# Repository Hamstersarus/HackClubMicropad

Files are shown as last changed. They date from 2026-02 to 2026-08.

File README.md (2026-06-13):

# HackClubMicropad

---

## Table of Contents

- [Overview](#overview)
- [Photos](#photos)
- [Bill of Materials](#bill-of-materials)

---

## Overview

The HackClub Micropad is a compact, USB-HID macropad intended for programmable shortcut input.
It was designed from scratch in KiCad and manufactured via JLCPCB. Firmware runs on CircuitPython.
It is a keybord with a programmable OLED screen, 6 keys, and a rotary encoder.
It is a fun, memorable, and beginner friendly productivity tool.

**Key features:**

- Seeed Studio XIAO RP2350 microcontroller
- Mechanical key switches (MX-compatible footprints)
- Rotary encoder with push-button
- Onboard NeoPixel (WS2812B) RGB indicator
- USB-C connectivity via the XIAO module
- 3D-printed enclosure (FDM, PLA)

---

## Photos

**PCB Top View**

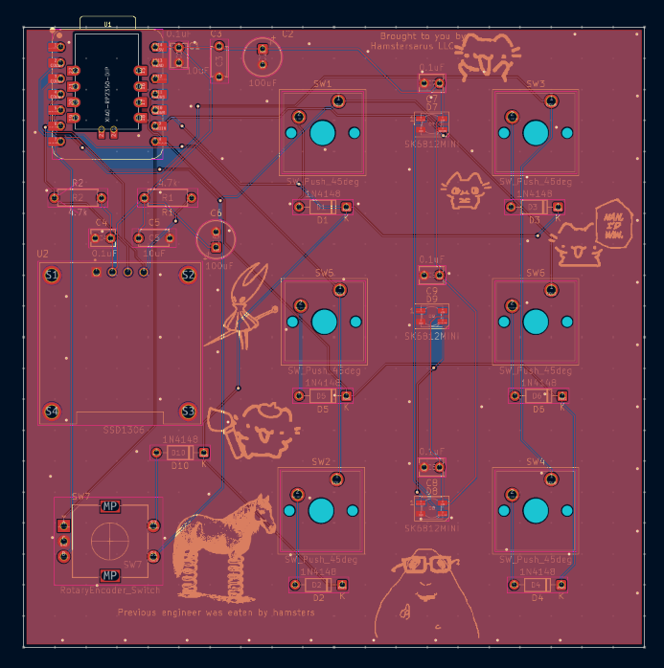
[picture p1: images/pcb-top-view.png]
PCB top view


**Assembled Board**

snapshot_assembly

**Case**

snapshot_case_only_back

snapshot_case_only_front

---

### Bill of Materials

| Part Number | Description | Quantity | Ordering Location |
| :--- | :--- | :--- | :--- |
| 1597-102010550-ND | Seeed Studio XIAO RP2350 microcontroller (DIP) | 1 | [DigiKey](https://www.digikey.com/en/products/result?keywords=1597-102010550-ND) |
| 4809-EC11E15204A3-ND | EC11 rotary encoder with push-button, 5-pin | 1 | [DigiKey](https://www.digikey.com/en/products/detail/alps-alpine/EC11E15204A3/21721644) |
| 3086-MDOB128064V2V-YI-ND | SSD1306 OLED Screen | 1 | [DigiKey](https://www.digikey.com/en/products/detail/midas-displays/MDOB128064V2V-YI/20842029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) |
| 1528-1541-ND | RGB LED with integrated controller (SK6812MINI) | 3 | [DigiKey](https://www.digikey.com/en/products/detail/adafruit-industries-llc/2686/5804107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) |
| 1644-MX2A-E1NW-ND | Push button switch, normally open, 45° tilted | 6 | [DigiKey](https://www.digikey.com/en/products/detail/cherry-americas-llc/MX2A-E1NW/21738396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) |
| 1N4148FS-ND | 100V 0.15A standard switching diode, DO-35 | 7 | [DigiKey](https://www.digikey.com/en/products/detail/onsemi/1N4148/458603?s=N4IgTCBcDaIIwDkAsckA4BiBlAtAgIiALoC%2BQA) |
| 490-8808-ND | Unpolarized capacitor, 0.1uF | 5 | [DigiKey](https://www.digikey.com/en/products/detail/murata-electronics/RDER71E104K0K1H03B/4770963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) |
| 399-C324C106K3R5TA7301CT-ND | Unpolarized capacitor, 10uF | 2 | [DigiKey](https://www.digikey.com/en/products/detail/kemet/C324C106K3R5TA7301/12699356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) |
| 732-8825-1-ND | Polarized capacitor, 100uF | 2 | [DigiKey](https://www.digikey.com/en/products/result?keywords=732-8825-1-ND) |
| 56-CCF554K70FKE36CT-ND | Resistor, 4.7k | 2 | [DigiKey](https://www.digikey.com/en/products/detail/vishay-beyschlag-draloric-bc-components/CCF554K70FKE36/28262019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) |

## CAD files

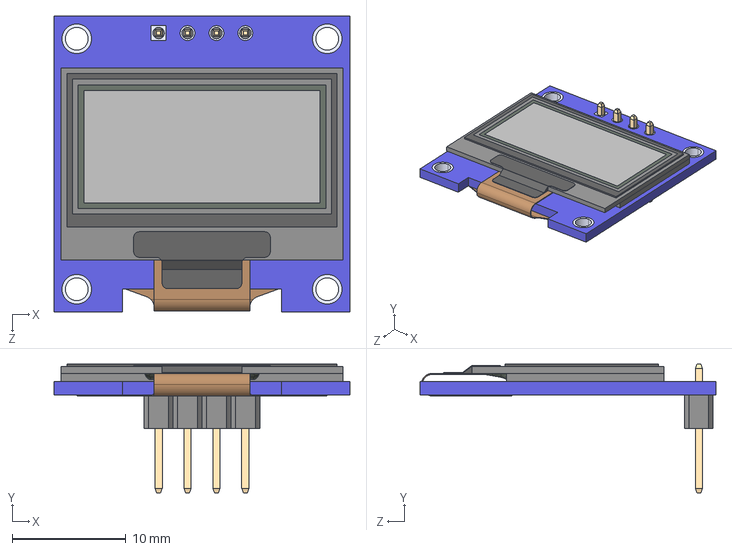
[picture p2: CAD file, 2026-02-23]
KiCAD/Symbols/DM-OLED096-636/DM-OLED096-636.step
26.0 x 11.3 x 26.0 mm
DM-OLED096-636_Module
DM-OLED096-636_Panel

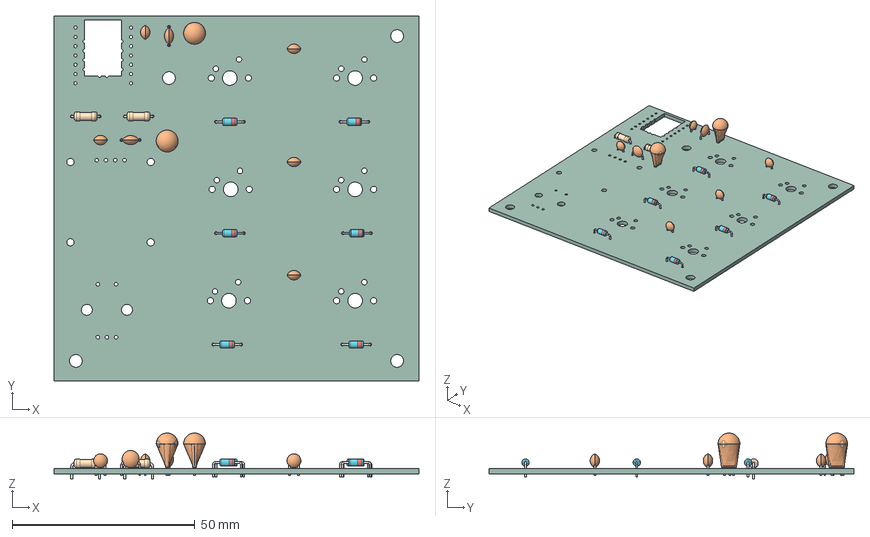
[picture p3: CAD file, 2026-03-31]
Mechanical/Models/Macropad.step
100.0 x 100.0 x 12.6 mm
C_Disc_D3.8mm_W2.6mm_P2.50mm x 5
D_DO-35_SOD27_P7.62mm_Horizontal x 6
R_Axial_DIN0207_L6.3mm_D2.5mm_P7.62mm_Horizontal x 2
C_Disc_D4.7mm_W2.5mm_P5.00mm x 2
CP_Radial_Tantal_D6.0mm_P2.50mm x 2
Macropad_PCB

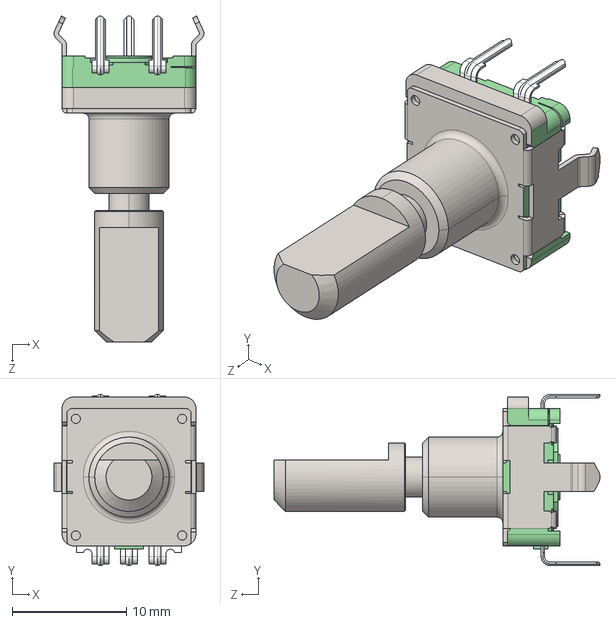
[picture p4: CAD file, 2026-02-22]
KiCAD/Symbols/EC1110120201_Rotary_Encoder/3D/EC1110120201.stp
13.1 x 15.0 x 28.5 mm

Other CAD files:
KiCAD/Symbols/EC1110120201_Rotary_Encoder/Allegro/ec1110120201.psm
KiCAD/Symbols/EC1110120201_Rotary_Encoder/DEHDL/ec1110120201/chips/chips.prt

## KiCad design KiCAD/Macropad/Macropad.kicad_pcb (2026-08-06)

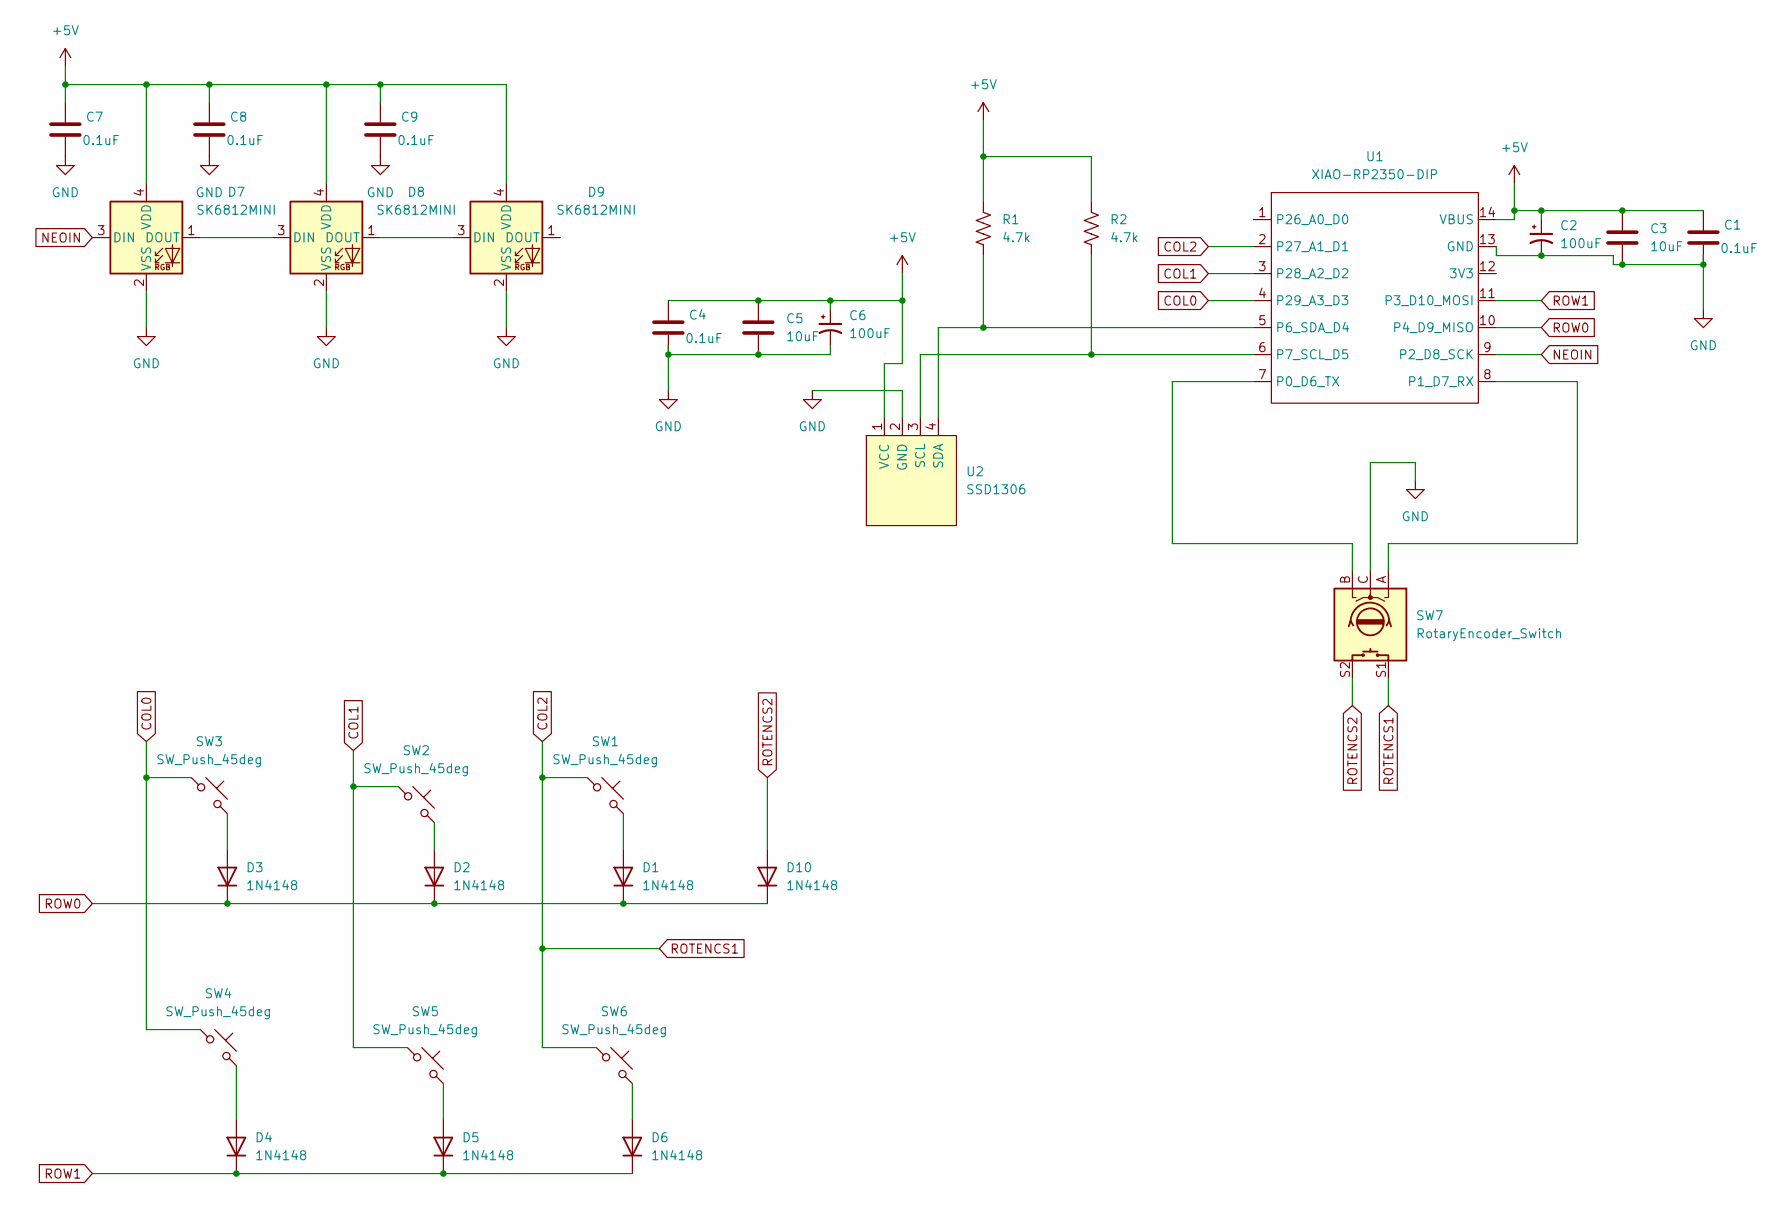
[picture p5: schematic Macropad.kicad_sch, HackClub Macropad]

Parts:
C1, C4, C7, C8, C9: 0.1uF; C_Disc_D3.8mm_W2.6mm_P2.50mm; Part_Number 490-8808-ND
C2, C6: 100uF; CP_Radial_Tantal_D6.0mm_P2.50mm; Part_Number 732-8825-1-ND
C3, C5: 10uF; C_Disc_D4.7mm_W2.5mm_P5.00mm; Part_Number 399-C324C106K3R5TA7301CT-ND
D1, D2, D3, D4, D5, D6, D10: 1N4148; D_DO-35_SOD27_P7.62mm_Horizontal; Part_Number 1N4148FS-ND
D7, D8, D9: SK6812MINI; LED_SK6812MINI_PLCC4_3.5x3.5mm_P1.75mm; Part_Number 1528-1541-ND
R1, R2: 4.7k; R_Axial_DIN0207_L6.3mm_D2.5mm_P7.62mm_Horizontal; Part_Number 56-CCF554K70FKE36CT-ND
SW1, SW2, SW3, SW4, SW5, SW6: SW_Push_45deg; SW_Cherry_MX_1.00u_PCB; Part_Number 1644-MX2A-E1NW-ND
SW7: RotaryEncoder_Switch; RotaryEncoder_Alps_EC11E-Switch_Vertical_H20mm; Part_Number 4809-EC11E15204A3-ND
U1: XIAO-RP2350-DIP; Part_Number 1597-102010550-ND
U2: SSD1306; MODULE_DM-OLED096-636; Part_Number 3086-MDOB128064V2V-YI-ND

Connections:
+5V: C1.1, C2.1, C3.1, C4.1, C5.1, C6.1, C7.1, C8.1, C9.1, D7.4 (VDD), D8.4 (VDD), D9.4 (VDD), R1.2, R2.2, U1.14 (VBUS), U2.1 (VCC)
COL0: SW3.1, SW4.1, U1.4 (P29_A3_D3)
COL1: SW2.1, SW5.1, U1.3 (P28_A2_D2)
COL2: SW1.1, SW6.1, SW7.S1, U1.2 (P27_A1_D1)
GND: C1.2, C2.2, C3.2, C4.2, C5.2, C6.2, C7.2, C8.2, C9.2, D7.2 (VSS), D8.2 (VSS), D9.2 (VSS), SW7.C, U1.13 (GND), U2.2 (GND)
NEOIN: D7.3 (DIN), U1.9 (P2_D8_SCK)
unnamed: D1.2 (A), SW1.2
unnamed: D2.2 (A), SW2.2
unnamed: D3.2 (A), SW3.2
unnamed: D4.2 (A), SW4.2
unnamed: D5.2 (A), SW5.2
unnamed: D6.2 (A), SW6.2
unnamed: D7.1 (DOUT), D8.3 (DIN)
unnamed: D8.1 (DOUT), D9.3 (DIN)
unnamed: SW7.B, U1.7 (P0_D6_TX)
unnamed: SW7.A, U1.8 (P1_D7_RX)
unnamed: R1.1, U1.5 (P6_SDA_D4), U2.4 (SDA)
unnamed: R2.1, U1.6 (P7_SCL_D5), U2.3 (SCL)
ROTENCS2: D10.2 (A), SW7.S2
ROW0: D1.1 (K), D2.1 (K), D3.1 (K), D10.1 (K), U1.10 (P4_D9_MISO)
ROW1: D4.1 (K), D5.1 (K), D6.1 (K), U1.11 (P3_D10_MOSI)

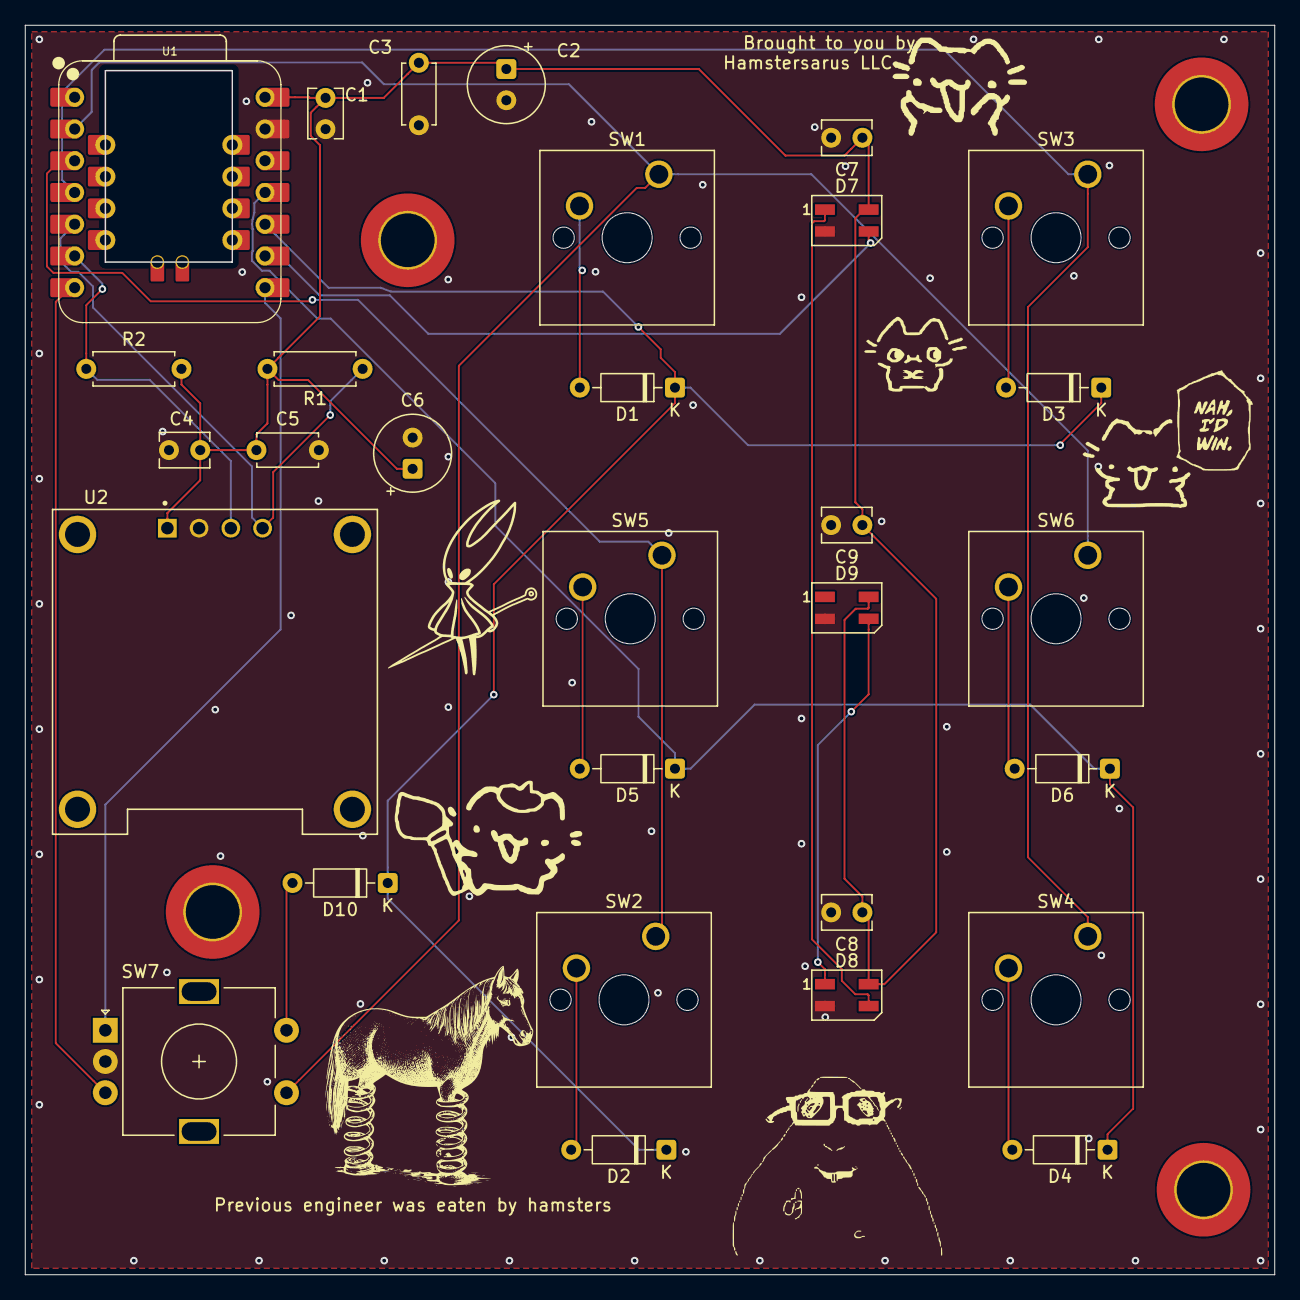
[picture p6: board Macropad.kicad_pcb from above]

Board: 2 copper layers, 100.0 x 100.0 mm, 35 parts (0 on the bottom side), 21 nets.

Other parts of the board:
Brought to you by Hamstersarus LLC: LOGO
REF1, REF2, REF3, REF4: MountingHole_4.3mm_M4_DIN965_Pad_TopBottom

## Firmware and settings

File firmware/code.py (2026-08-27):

## HackClub Macropad — KMK firmware with on-demand video playback
## Board: Seeed XIAO RP2350 (U1)
##
## Matrix (2 rows x 3 cols), diodes anode->switch->COL, cathode->ROW:
##   physical layout is 2 cols x 3 rows; see keymap comments for the mapping.
## Encoder (SW7): A=D6  B=D7  C=GND  (rotation = volume; turn-only)
## OLED (SSD1306, U2) I2C: SDA=D4  SCL=D5  addr=0x3C  (raw driver, 400kHz)
##
## Video: the top-left key sends "PLAY" over the USB *data* serial (enabled in
## boot.py). The host companion (host/play_companion.py) then streams 1024-byte
## OLED frames back over that channel while playing the audio on the computer.
## This module blits incoming frames to the OLED between matrix scans.

import board
import busio
import usb_cdc

from kmk.kmk_keyboard import KMKKeyboard
from kmk.keys import KC, make_key
from kmk.scanners import DiodeOrientation
from kmk.modules import Module
from kmk.extensions.media_keys import MediaKeys

import rotaryio

W, H = 128, 64
FRAME = W * H // 8  # 1024
ADDR = 0x3C
INIT = bytes([0xAE, 0xD5, 0x80, 0xA8, 0x3F, 0xD3, 0x00, 0x40, 0x8D, 0x14,
              0x20, 0x00, 0xA1, 0xC8, 0xDA, 0x12, 0x81, 0x7F, 0xD9, 0xF1,
              0xDB, 0x40, 0xA4, 0xA6, 0x2E, 0xAF])


class OLED:
    """Minimal raw SSD1306 128x64 driver — fast full-frame blits."""
    def __init__(self, scl, sda):
        self.i2c = busio.I2C(scl, sda, frequency=400_000)  # SSD1306 max
        while not self.i2c.try_lock():
            pass
        self.i2c.writeto(ADDR, b"\x00" + INIT)
        self._win = bytes([0x00, 0x21, 0, 127, 0x22, 0, 7])
        self._out = bytearray(1 + FRAME)
        self._out[0] = 0x40

    def show(self, buf):
        self.i2c.writeto(ADDR, self._win)
        self._out[1:] = buf
        self.i2c.writeto(ADDR, self._out)


def _load(path, default=b"\x00" * FRAME):
    try:
        with open(path, "rb") as f:
            d = f.read(FRAME)
        return d if len(d) == FRAME else default
    except OSError:
        return default


class VideoModule(Module):
    """Streams OLED frames from the USB data serial, between KMK scans."""
    def __init__(self):
        self.oled = OLED(board.D5, board.D4)
        self.splash = _load("/splash.bin")
        self.ser = usb_cdc.data
        self.frame = bytearray(FRAME)
        self.view = memoryview(self.frame)
        self.fill = 0

    def during_bootup(self, keyboard):
        self.oled.show(self.splash)

    def before_matrix_scan(self, keyboard):
        ser = self.ser
        if ser is not None and ser.in_waiting:
            self.fill += ser.readinto(self.view[self.fill:])
            if self.fill >= FRAME:
                self.oled.show(self.frame)
                self.fill = 0

    def after_matrix_scan(self, keyboard):
        pass

    def before_hid_send(self, keyboard):
        pass

    def after_hid_send(self, keyboard):
        pass

    def on_powersave_enable(self, keyboard):
        pass

    def on_powersave_disable(self, keyboard):
        pass


keyboard = KMKKeyboard()
keyboard.extensions.append(MediaKeys())

video = VideoModule()
keyboard.modules.append(video)

# Video control keys: signal the host companion over the USB data serial.
def _play(*args):
    if usb_cdc.data is not None:
        usb_cdc.data.write(b"PLAY\n")

def _stop(*args):
    if usb_cdc.data is not None:
        usb_cdc.data.write(b"STOP\n")

make_key(names=("VPLAY",), on_press=_play)
make_key(names=("VSTOP",), on_press=_stop)

# --- Key matrix ---
keyboard.col_pins = (board.D3, board.D2, board.D1)   # COL0, COL1, COL2
keyboard.row_pins = (board.D9, board.D10)            # ROW0, ROW1
keyboard.diode_orientation = DiodeOrientation.COL2ROW

# --- Encoder (volume), hardware-decoded --------------------------------
# rotaryio counts in the RP2350's PIO, so turns are never missed even when a
# video blit stalls the main loop (KMK's software GPIO encoder mis-decodes
# there). We tap VOLU/VOLD from the accumulated count, one step per scan.
class HWVolumeEncoder(Module):
    def __init__(self, pin_a, pin_b, cw=KC.VOLU, ccw=KC.VOLD):
        self.enc = rotaryio.IncrementalEncoder(pin_a, pin_b)
        self.cw = cw
        self.ccw = ccw
        self.last = 0
        self.pending = 0

    def during_bootup(self, keyboard):
        self.last = self.enc.position

    def before_matrix_scan(self, keyboard):
        pos = self.enc.position
        if pos != self.last:
            self.pending += pos - self.last
            self.last = pos
        if self.pending > 0:
            self.pending -= 1
            keyboard.tap_key(self.cw)
        elif self.pending < 0:
            self.pending += 1
            keyboard.tap_key(self.ccw)

    def after_matrix_scan(self, keyboard): pass
    def before_hid_send(self, keyboard): pass
    def after_hid_send(self, keyboard): pass
    def on_powersave_enable(self, keyboard): pass
    def on_powersave_disable(self, keyboard): pass

keyboard.modules.append(HWVolumeEncoder(board.D6, board.D7))

# --- Keymap ---
# Physical 2 cols x 3 rows. Electrical scan order is row0 then row1, col0..col2.
#   top-left = PLAY video       top-right = STOP video
#   mid-left = c                mid-right = d
#   bot-left = e                bot-right = f
keyboard.keymap = [
    [
        # ROW0:  SW3(top-right)   SW2(bot-left)   SW1(top-left)
        KC.VSTOP,        KC.E,           KC.VPLAY,
        # ROW1:  SW4(bot-right)   SW5(mid-left)   SW6(mid-right)
        KC.F,            KC.C,           KC.D,
    ],
]

if __name__ == '__main__':
    keyboard.go()

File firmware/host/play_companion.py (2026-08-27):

#!/usr/bin/env python3
"""Companion player: streams packed OLED frames to the macropad over the USB data
serial while playing the audio on this computer, kept in sync by pacing both from
one clock here.

Modes:
  --now         stream immediately, once (Stage-A test)
  (default)     wait for the board to send 'PLAY' (Stage-B: play on keypress),
                then stream + play audio; loops so you can trigger it repeatedly.
"""
import argparse
import glob
import subprocess
import sys
import time

import serial  # pyserial

FRAME = 128 * 64 // 8  # 1024


def find_data_port():
    # The data channel enumerates as the if02 interface; console is if00.
    for p in sorted(glob.glob("/dev/serial/by-id/*XIAO*")):
        if "if02" in p:
            return p
    # Fallback: second ACM device
    acms = sorted(glob.glob("/dev/ttyACM*"))
    return acms[1] if len(acms) > 1 else (acms[0] if acms else None)


def load_frames(path):
    with open(path, "rb") as f:
        data = f.read()
    return [data[i:i + FRAME] for i in range(0, len(data) - FRAME + 1, FRAME)]


def load_splash(path):
    try:
        with open(path, "rb") as f:
            d = f.read(FRAME)
        return d if len(d) == FRAME else None
    except OSError:
        return None


def stream(ser, frames, fps, audio, splash=None):
    proc = None
    if audio:
        proc = subprocess.Popen(
            ["ffplay", "-nodisp", "-autoexit", "-loglevel", "quiet", audio]
        )
    ser.reset_input_buffer()  # drop the PLAY token / stale bytes
    t0 = time.monotonic()
    grace = 1.0               # ignore STOP for the first second (play-press residue)
    rx = b""
    stopped = False
    try:
        for i, fr in enumerate(frames):
            if ser.in_waiting:
                rx += ser.read(ser.in_waiting)
            elapsed = time.monotonic() - t0
            if elapsed < grace:
                rx = b""            # discard any residue during the grace window
            elif b"STOP" in rx:     # a real stop press after playback is underway
                stopped = True
                break
            if b"PLAY" in rx:       # ignore repeated play presses
                rx = b""
            if proc and proc.poll() is not None:
                break
            target = t0 + i / fps
            dt = target - time.monotonic()
            if dt > 0:
                time.sleep(dt)
            ser.write(fr)
    finally:
        if proc and proc.poll() is None:
            proc.terminate()          # stop audio immediately on STOP
        if proc:
            proc.wait()
        if splash:
            ser.write(splash)         # return the OLED to the title card
    print("STOPPED" if stopped else f"finished ({len(frames)/fps:.1f}s)")


def main():
    ap = argparse.ArgumentParser()
    ap.add_argument("--frames", default="frames.bin")
    ap.add_argument("--audio", default="badapple.mp3")
    ap.add_argument("--fps", type=int, default=30)
    ap.add_argument("--port", default=None)
    ap.add_argument("--splash", default="splash.bin")
    ap.add_argument("--now", action="store_true", help="stream once immediately")
    args = ap.parse_args()

    frames = load_frames(args.frames)
    print(f"loaded {len(frames)} frames from {args.frames}")
    splash = load_splash(args.splash)

    if args.now:
        port = args.port or find_data_port()
        if not port:
            sys.exit("No data serial port found. Is boot.py enabling usb_cdc.data?")
        stream(serial.Serial(port, 115200, timeout=0.1),
               frames, args.fps, args.audio, splash)
        return

    # Resilient loop: wait for the board, serve PLAY presses, recover from unplugs.
    print("companion running — waiting for the board / play key...  Ctrl-C to quit")
    while True:
        port = args.port or find_data_port()
        if not port:
            time.sleep(2)          # board not plugged in yet; keep waiting
            continue
        try:
            ser = serial.Serial(port, 115200, timeout=0.1)
            print(f"connected: {port}")
            pending = b""
            while True:
                pending += ser.read(64)
                if b"PLAY" in pending:
                    pending = b""
                    print("PLAY received -> starting")
                    stream(ser, frames, args.fps, args.audio, splash)
                    print("waiting for next PLAY...")
        except (serial.SerialException, OSError):
            print("board disconnected — waiting for it to come back...")
            time.sleep(2)          # unplugged mid-run; retry the connection


if __name__ == "__main__":
    main()

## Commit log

2026-01-31 Initial commit of BOM spreadsheet and datasheets.
    [Parts_List.ods]
2026-01-31 Made changes to parts list, added 3D model and KiCad sch and pcb symbols for the Raspberry Pi Pico H.
    [Parts_List.ods, Pi_Pico_H.STEP]
2026-02-16 Created schematic symbol for rp2040 cpu and added its libraries.
    [Macropad.kicad_pcb, Macropad.kicad_sch]
2026-02-16 Added roatary encoder and libraries.
    [Macropad.kicad_sch]
2026-02-22 Updated schematic with push buttons and rotary encoder.
    [EC1110120201.PcbLib, EC1110120201.SchLib, EC1110120201.stp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]
2026-02-23 Added majority of components to schematic. :)
    [DM-OLED096-636.step, Macropad.kicad_sch]
2026-02-23 Added diodes and ports, finished schematic :D.
    [Macropad.kicad_sch]
2026-02-24 Added footprints for rotary encoder and rp2040.
    [Macropad.kicad_sch]
2026-02-25 Made updates to BOM.
    [Parts_List.ods]
2026-03-31 Initial candidate for layout
    [Macropad.kicad_pcb, Macropad.kicad_sch]
2026-03-31 Finished board wiring, layout, silkscreen, removed unneeded files, added case 3D model.
    [Macropad.kicad_pcb, Macropad.step, Pi_Pico_H.STEP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]
2026-04-01 Update README.md
    Wrote the README, everything except a 3D model of the board in the case.
2026-04-01 Update README.md
    Added the screenshot of the board in the case.
2026-04-01 Added assembly: case+board
    [assembly.step]
2026-04-20 Changed pictures for the case and the assembled view
2026-04-20 Fixed case
    [assembly.step, case.step]
2026-06-03 Fixed some shorts in the matrix.
    [Macropad.kicad_sch]
2026-06-08 Updated schematic and layout with new EC11 rotary encoder.
    [Macropad.kicad_pcb, Macropad.kicad_sch]
2026-06-13 Reorganize XIAO footprints into .pretty library
2026-06-13 Update layout, schematic, and interactive BOM with part numbers
    [Macropad.kicad_pcb, Macropad.kicad_sch, Parts_List.ods]
2026-06-13 Add v001 Gerber manufacturing output
    [Macropad-B_Paste.gbr, Macropad-Board Layer Stack Bottom Overlay.gbr, Macropad-Board Layer Stack Bottom Solder.gbr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]
2026-06-13 Updated README DOM and PCB top-view image
2026-06-22 Fixed a crossed wire issue and an issue with my microcontroller.
    [Macropad-B_Paste.gbr, Macropad-Board Layer Stack Bottom Overlay.gbr, Macropad-Board Layer Stack Bottom Solder.gbr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]
2026-08-06 Re-save PCB (formatting/precision only, no layout change)
    [Macropad.kicad_pcb]
2026-08-27 Added a new driver and made the user able to watch a video on the screen (currently its bad apple cause duh). It only works when the companion is running on pc but thats only temporary.
2026-08-27 updated kicad project file
2026-08-27 Fixed funky knob while the video was playing.
    [code.py]
